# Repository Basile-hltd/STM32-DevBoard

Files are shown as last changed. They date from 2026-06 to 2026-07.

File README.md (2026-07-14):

# STM32 Dev Board

Carte de développement autour d'un microcontrôleur STM32, conçue pour l'acquisition de données environnementales, la communication industrielle et l'expansion vers breadboard ou systèmes embarqués tiers.

> **Contenu actuel du dépôt :**
>- projet KiCad (schématique + layout PCB).
>- Lib static HAL (propre à ce PCB).
>- Projects exemple (utilisant la lib)

---

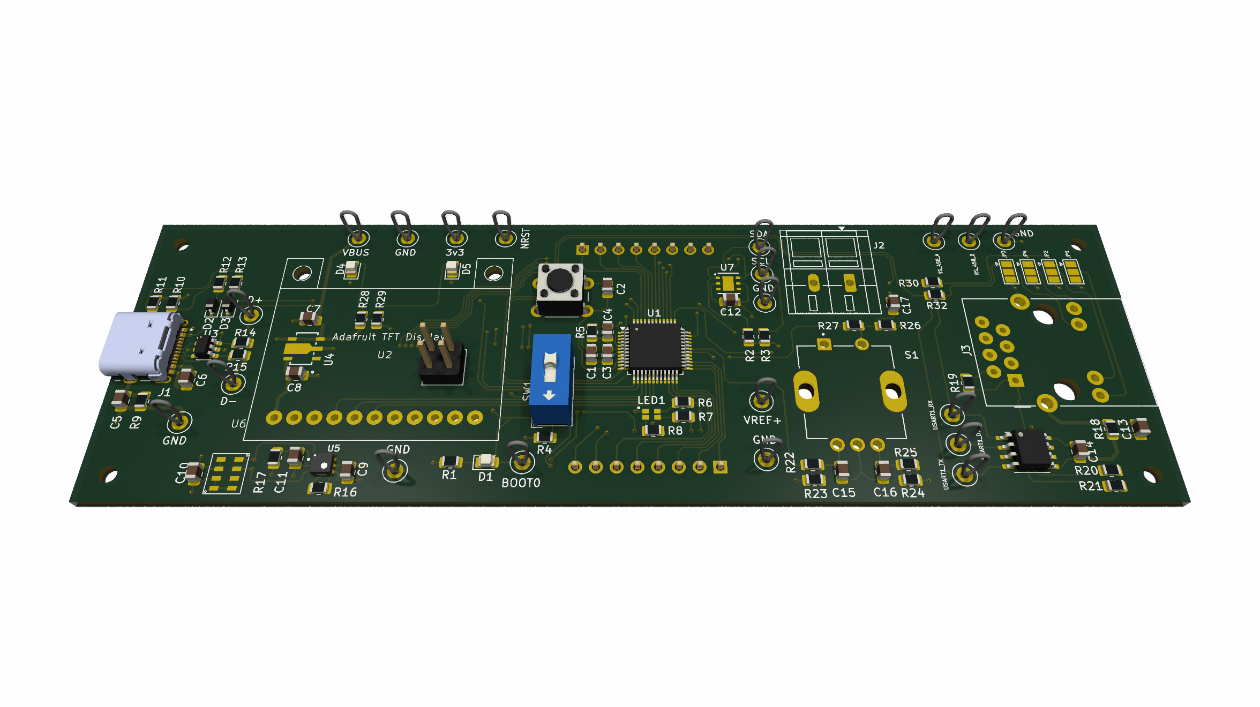
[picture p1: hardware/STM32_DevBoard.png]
Schéma bloc de la carte


## Fonctionnalités PCB

### I²C - Capteur
Quatre capteurs partagent le même bus I²C :
- Pression barométrique
- Qualité de l'air (COV / CO₂ équivalent)
- Température
- Humidité relative

### SPI - Affichage & stockage
- Écran (Color TFT 160x80)
- Carte microSD

### USB
Connecteur **USB-C** câblé directement au microcontrôleur (Full-Speed).

### RS-485
Port **RJ45** utilisé comme connecteur de terrain pour un bus **RS-485** :
- Piloté via **UART** du MCU
- **Pin de direction** (DE/RE) exposé pour la gestion half-duplex
- Alimentation **48 V** optionnelle injectée sur le bus RS-485 et sur le RJ45 via un connecteur **Wago** monté sur la carte (alimentation fantôme ou PoE industriel)

### Interface utilisateur
- **LED RGB**
- **Encodeur rotatif** avec bouton-poussoir

### Port B - Extension
Deux **pin headers 8 broches** (2 × 8 = 16 broches) exposant l'intégralité du **Port B** du STM32. Permet de connecter la carte à une breadboard, un shield ou tout autre sous-système externe sans soudure.

---

## Structure du dépôt

```
C:.
│   README.md
│   
├───documentation
│   │   .gitignore
│   │   *.pdf
│   │   
│   ├───datasheet
│   │       *.pdf
│   │       
│   └───script
│           Datasheet_Downloader.py
│           Digikey_Datasheet_List.csv
│           requirements.txt
│           
├───hardware
│   │   .gitignore
│   │   STM32_DevBoard.kicad_pcb
│   │   STM32_DevBoard.kicad_prl
│   │   STM32_DevBoard.kicad_pro
│   │   STM32_DevBoard.kicad_sch
│   │   STM32_DevBoard.pdf
│   │   STM32_DevBoard.png
│   │       
│   ├───3d_models
│   │       *.step
│   │       
│   ├───footprints
│   │       *.kicad_mod
│   │       
│   └───symbols
│           *.kicad_sym
│           
└───software
    │   .gitignore
    │   arm-none-eabi.cmake
    │   CMakeLists.txt
    │   stm32c0.ld
    │           
    ├───Blinky
    │   │   CMakeLists.txt
    │   │   
    │   └───src
    │           main.c
    │                       
    └───DevBoard_HAL
        │   CMakeLists.txt
        │   
        └───src
            │   init.c
            │   rgb_led.c
            │   startup.c
            │   
            └───headers
                    init.h
                    registers.h
                    rgb_led.h
                    STM32_DevBoard.h
                    
```

---

## Prérequis

- **KiCad 8.x** ou supérieur
- Bibliothèques KiCad standard 
- CMake
- arm-none-eabi
- dfu-util
- STM32Cube-Programmer
---

## Mise en route

### Compilation
crée un dossier build dans `software/`, initialiser cmake, puis compiler.

```
mkdir software/build
cd software/build
cmake -DCMAKE_TOOLCHAIN_FILE="../arm-none-eabi.cmake" ..
```
compiler avec :

```
cmake --build .
```

ou flasher avec

```
cmake --build . --target flash_{nom du dossier d'app}
cmake --build . --target flash_Blinky
```

Cela va buils le HAL ainsi que toutes la applications. Le premier build peut prendre plus de temps. Les binaire des applications se trouvent dans `software/bin/le_nom_de_lapp/`

---

## Futures Amleliorations

- Ajuster les dimension du PCB
- Réduire la taille du PCB
- Ajout de pin d'alimentation et de masse sur les pin du port B
- Diodes TVS et sécurité sur bus RS_485 (Alim et signaux)
- Implémenter protocole power delivery USB-C (48V sur usb-c et non wage par exemple ou que le STM32 puisse connaitre les capacité de l'alim)

---

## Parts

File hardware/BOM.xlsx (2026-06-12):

Reference | Qty | Value | In Degikey list
C1,C2,C3,C5,C6,C10,C12,C13,C14 | 9 | 100nF | Y
C4 | 1 | 4.7uF | Y
C7 | 1 | 10uF | Y
C8,C9,C11 | 3 | 1uF | Y
C15,C16,C17 | 3 | 10nF | Y
D1 | 1 | BOOT0_LED | Y
D2,D3 | 2 | CC
D4 | 1 | VBUS_LED
D5 | 1 | 3v3_LED
J1 | 1 | USB4105-GF-A
J2 | 1 | Screw_Terminal_01x02
J3 | 1 | RJ45_LED_Shielded
J5 | 1 | Port_B_1
J6 | 1 | Port_B_2
LED1 | 1 | IN-S66TBTRGB
R1 | 1 | 150
R2,R3 | 2 | 3k3
R4,R22,R23,R24,R25,R26,R27 | 7 | 10k
R5,R16 | 2 | 0
R6,R28 | 2 | 560
R7,R8 | 2 | 360
R9,R18 | 2 | 1M
R10,R11 | 2 | 5k1
R12,R13 | 2 | 100
R14,R15 | 2 | 22
R17 | 1 | 4.7
R19 | 1 | 120
R20,R21 | 2 | 1k
R29 | 1 | 220
S1 | 1 | PEC12R-4217F-S0012
SW1 | 1 | SW_SPST
SW2 | 1 | SW_MEC_5G
TP1,TP7,TP8,TP13,TP14,TP18 | 6 | GND
TP2 | 1 | SDA
TP3 | 1 | SCL
TP4 | 1 | BOOT0
TP5 | 1 | VREF+
TP6 | 1 | NRST
TP9 | 1 | D+
TP10 | 1 | D-
TP11 | 1 | VBUS
TP12 | 1 | 3v3
TP15 | 1 | USART1_DE
TP16 | 1 | USART1_RX
TP17 | 1 | USART1_TX
TP19 | 1 | RS_458_B
TP20 | 1 | RS_458_A
U1 | 1 | STM32C071CBTx
U2 | 1 | DISPLAY TFT
U3 | 1 | USBLC6-2SC6
U4 | 1 | AP2112R5-3.3TRG1
U5 | 1 | SGP40-D-R4
U6 | 1 | MS5607-02BA
U7 | 1 | HDC1080
U8 | 1 | TP8485E-SR

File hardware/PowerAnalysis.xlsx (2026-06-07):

 |  |  |  |  |  |  |  | VBUS
3.3 | V |  |  |  |  | mA | mW | 5 | V |  |  |  |  | mA | mW
 |  | Name | Current[mA] | Power [mW] | Total | 140.553 | 463.8249 |  |  | Name | Current[mA] | Power [mW] | Total | 160.613 | 803.065
 |  | I2C | 2 | 6.6 |  |  |  |  |  | Led RGB | 15 | 75
 |  | STM32 | 100 | 330 |  |  |  |  |  | Led Alim | 5 | 25
 |  | BOOT0 | 0.33 | 1.089 |  |  |  |  |  | AP211 | 140.613 | 703.065
 |  | Screen | 25 | 82.5
 |  | Alim LED | 5 | 16.5
 |  | SGP40 | 3 | 9.9
 |  | HDC1080 | 0.22 | 0.726
 |  | MS5607 | 0.013 | 0.0429
 |  | TP8485 | 1 | 3.3
 |  | LED RJ45 | 3 | 9.9
 |  | Encodeur | 0.99 | 3.267

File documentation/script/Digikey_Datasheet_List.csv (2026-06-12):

Index | Référence fabricant | Nom du fabricant | Description | Fiche technique | Notes sur le produit
1 | CL21B104KBCNNNC | Samsung Electro-Mechanics | CAP CER 0.1UF 50V X7R 0805 | https://mm.digikey.com/Volume0/opasdata/d220001/medias/docus/609/CL21B104KBCNNN_Spec.pdf
2 | CL21A475KPFNNNE | Samsung Electro-Mechanics | CAP CER 4.7UF 10V X5R 0805 | https://weblib.samsungsem.com/mlcc/mlcc-ec-data-sheet.do?partNumber=CL05Y105KP6VPN
3 | CL21A106KPFNNNG | Samsung Electro-Mechanics | CAP CER 10UF 10V X5R 0805 | https://mm.digikey.com/Volume0/opasdata/d220001/medias/docus/658/CL21A106KPFNNNG.pdf
4 | CL21B105KAFNNNE | Samsung Electro-Mechanics | CAP CER 1UF 25V X7R 0805 | https://mm.digikey.com/Volume0/opasdata/d220001/medias/docus/1105/CL21B105KAFNNNE_Spec.pdf
5 | CL21B103KBANNNC | Samsung Electro-Mechanics | CAP CER 10000PF 50V X7R 0805 | https://www.samsungsem.com/kr/support/product-search/mlcc/CL21B103KBANNNC.jsp
6 | LTST-C170KRKT | Lite-On Inc. | LED RED CLEAR SMD | https://optoelectronics.liteon.com/upload/download/DS-22-99-0150/LTST-C170KRKT.pdf
7 | SDB13HS-AQ | Diotec Semiconductor | DIODE SCHOTTKY 30V 1A SOD323F | https://diotec.com/request/datasheet/sdb13hs.pdf
8 | LTST-C170KGKT | Lite-On Inc. | LED GREEN CLEAR SMD | https://optoelectronics.liteon.com/upload/download/DS22-2000-073/LTST-C170KGKT.pdf
9 | USB4105-GF-A | GCT | CONN RCP USB2.0 TYP C 16P SMD RA | https://gct.co/files/specs/usb4105-spec.pdf
10 | 236-102 | WAGO Corporation | PCB TERMINAL BLOCK; 2.5 MM; PIN | https://wago.priintcloud.com/datasheets/236-102/en/
11 | MTJ-88TX1-FSD-LG | Adam Tech | RJ45 MODULAR JACK, SHIELDED, DIP | https://app.adam-tech.com/products/download/data_sheet/203933/mtj-88tx1-fsd-lg-data-sheet.pdf
12 | 61300811121 | Würth Elektronik | CONN HEADER VERT 8POS 2.54MM | https://www.we-online.com/components/products/datasheet/61300811121.pdf
13 | IN-S66TBTRGB | Inolux | LED RGB CLEAR 0606 SMD | http://www.inolux-corp.com/datasheet/SMDLED/RGB%20Top%20View/IN-S66TBTRGB_V1.0.pdf
14 | RC0805FR-07150RL | YAGEO | RES 150 OHM 1% 1/8W 0805 | https://yageogroup.com/content/datasheet/asset/file/PYU-RC_GROUP_51_ROHS_L
15 | ERA-6AEB332V | Panasonic Industry | RES SMD 3.3K OHM 0.1% 1/8W 0805 | https://industrial.panasonic.com/cdbs/www-data/pdf/RDM0000/AOA0000C307.pdf
16 | RC0805FR-0710KL | YAGEO | RES 10K OHM 1% 1/8W 0805 | https://yageogroup.com/content/datasheet/asset/file/PYU-RC_GROUP_51_ROHS_L
17 | RMCF0805ZT0R00 | Stackpole Electronics Inc | RES 0 OHM JUMPER 1/8W 0805 | https://www.seielect.com/catalog/SEI-RMCF_RMCP.pdf
18 | ERJ-6GEYJ561V | Panasonic Industry | RES SMD 560 OHM 5% 1/8W 0805 | https://industrial.panasonic.com/cdbs/www-data/pdf/RDA0000/AOA0000C301.pdf
19 | RC0805JR-07360RL | YAGEO | RES 360 OHM 5% 1/8W 0805 | https://yageogroup.com/content/datasheet/asset/file/PYU-RC_GROUP_51_ROHS_L
20 | RG2012P-105-B-T5 | Susumu | RES SMD 1M OHM 0.1% 1/8W 0805 | https://www.susumu.co.jp/dl/?filename=n_catalog_partition01_en.pdf&type=application/pdf
21 | RC0805JR-075K1L | YAGEO | RES 5.1K OHM 5% 1/8W 0805 | https://yageogroup.com/content/datasheet/asset/file/PYU-RC_GROUP_51_ROHS_L
22 | RC0805FR-07100RL | YAGEO | RES 100 OHM 1% 1/8W 0805 | https://yageogroup.com/content/datasheet/asset/file/PYU-RC_GROUP_51_ROHS_L
23 | RC0805FR-0722RL | YAGEO | RES 22 OHM 1% 1/8W 0805 | https://yageogroup.com/content/datasheet/asset/file/PYU-RC_GROUP_51_ROHS_L
24 | RC0805JR-074R7L | YAGEO | RES 4.7 OHM 5% 1/8W 0805 | https://yageogroup.com/content/datasheet/asset/file/PYU-RC_GROUP_51_ROHS_L
25 | CRCW0805120RJNEA | Vishay Dale | RES SMD 120 OHM 5% 1/4W 0805 | https://www.vishay.com/docs/20035/dcrcwe3.pdf
26 | CRGCQ0805F220R | TE Connectivity Passive Product | RES 220 OHM 1% 1/8W 0805 | https://www.te.com/commerce/DocumentDelivery/DDEController?Action=srchrtrv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
27 | RR1220P-102-D | Susumu | RES SMD 1K OHM 0.5% 1/10W 0805 | https://www.susumu.co.jp/common/pdf/n_catalog_partition05_en.pdf
28 | PEC12R-4217F-S0012 | Bourns Inc. | ENCODER INCRE QUAD HORIZN PC PIN | https://www.bourns.com/docs/Product-Datasheets/PEC12R.pdf
29 | DS04-254-1L-01BK | Same Sky (Formerly CUI Devices) | SWITCH SLIDE DIP SPST 0.025A 24V | https://www.sameskydevices.com/product/resource/ds04-254.pdf
30 | TS02-66-50-BK-160-SCR-D | Same Sky (Formerly CUI Devices) | SWITCH TACTILE SPST-NO 0.05A 12V | https://www.sameskydevices.com/product/resource/ts02.pdf
31 | 4952 | Keystone Electronics | PC TEST POINT LOOP | https://www.keyelco.com/userAssets/file/K75p63.pdf
32 | STM32C071CBT7 | STMicroelectronics | STM32C | https://www.st.com/resource/en/datasheet/stm32c071r8.pdf
33 | 3533 | Adafruit Industries LLC | GRAPHIC DISPLAY TFT RGB 0.96" | https://cdn-learn.adafruit.com/downloads/pdf/adafruit-mini-tft-0-dot-96-inch-180x60-breakout.pdf
34 | USBLC6-2SC6 | Shenzhen Slkormicro Semicon Co., Ltd. | 6A@8/20US 13V 78W@8/20US 9V 5V S | https://mm.digikey.com/Volume0/opasdata/d220001/medias/docus/7833/USBLC6-2SC6%20SOT-23-6L.PDF
35 | AP2112R5-3.3TRG1 | Diodes Incorporated | IC REG LINEAR 3.3V 600MA SOT89-5 | https://www.diodes.com/assets/Datasheets/AP2112.pdf
36 | SGP40-D-R4 | Sensirion AG | SENSOR AIR QUALITY I2C OUTPUT | https://sensirion.com/media/documents/296373BB/6203C5DF/Sensirion_Gas_Sensors_Datasheet_SGP40.pdf
37 | MS560702BA03-50 | TE Connectivity Measurement Specialties | SENSOR 17.4PSIA 24BIT 8SMD | https://www.te.com/commerce/DocumentDelivery/DDEController?Action=srchrtrv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
38 | HDC1080DMBR | Texas Instruments | SENSOR HUMI/TEMP 3.3V I2C 2% SMD | https://www.ti.com/general/docs/suppproductinfo.tsp?distId=10
39 | TP8485E-SR | 3PEAK | IC TRANSCEIVER HALF 1/1 8SOIC | https://static.3peak.com/res/doc/ds/Datasheet_TP8485E.pdf

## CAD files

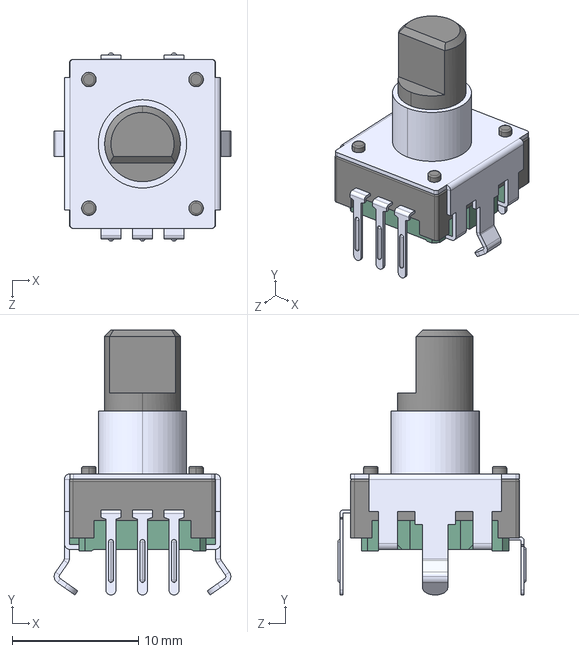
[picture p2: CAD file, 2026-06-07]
hardware/3d_models/PEC12R-4217F-S0012.step
14.0 x 21.0 x 14.9 mm

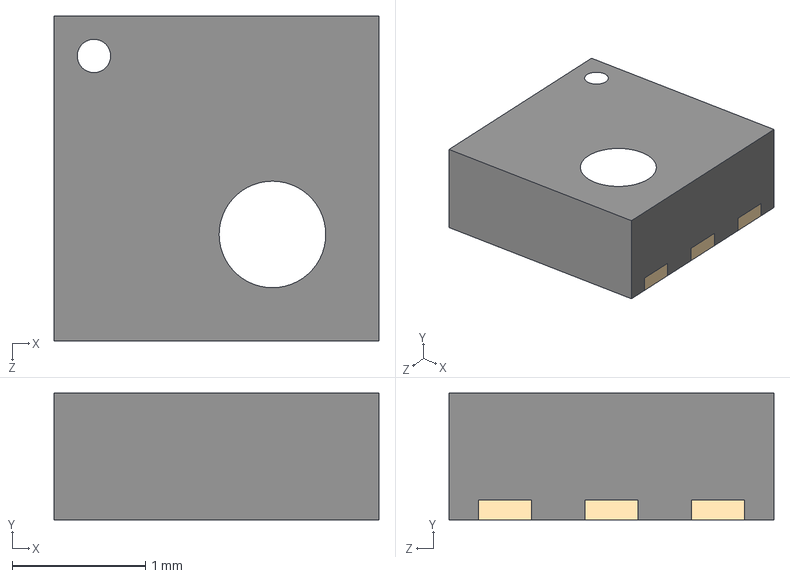
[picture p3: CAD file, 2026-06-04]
hardware/3d_models/SGP40-D-R4.step
2.44 x 0.95 x 2.44 mm

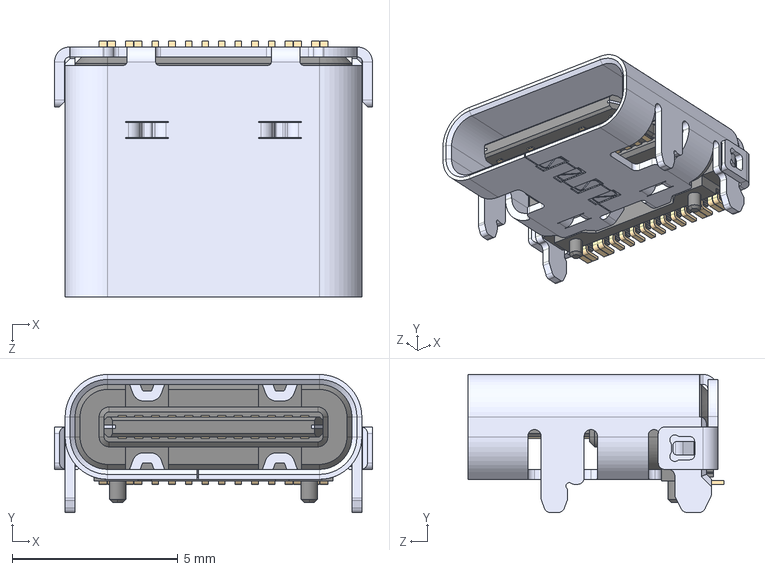
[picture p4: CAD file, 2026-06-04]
hardware/3d_models/USB4105-GF-A.step
9.58 x 4.16 x 7.71 mm

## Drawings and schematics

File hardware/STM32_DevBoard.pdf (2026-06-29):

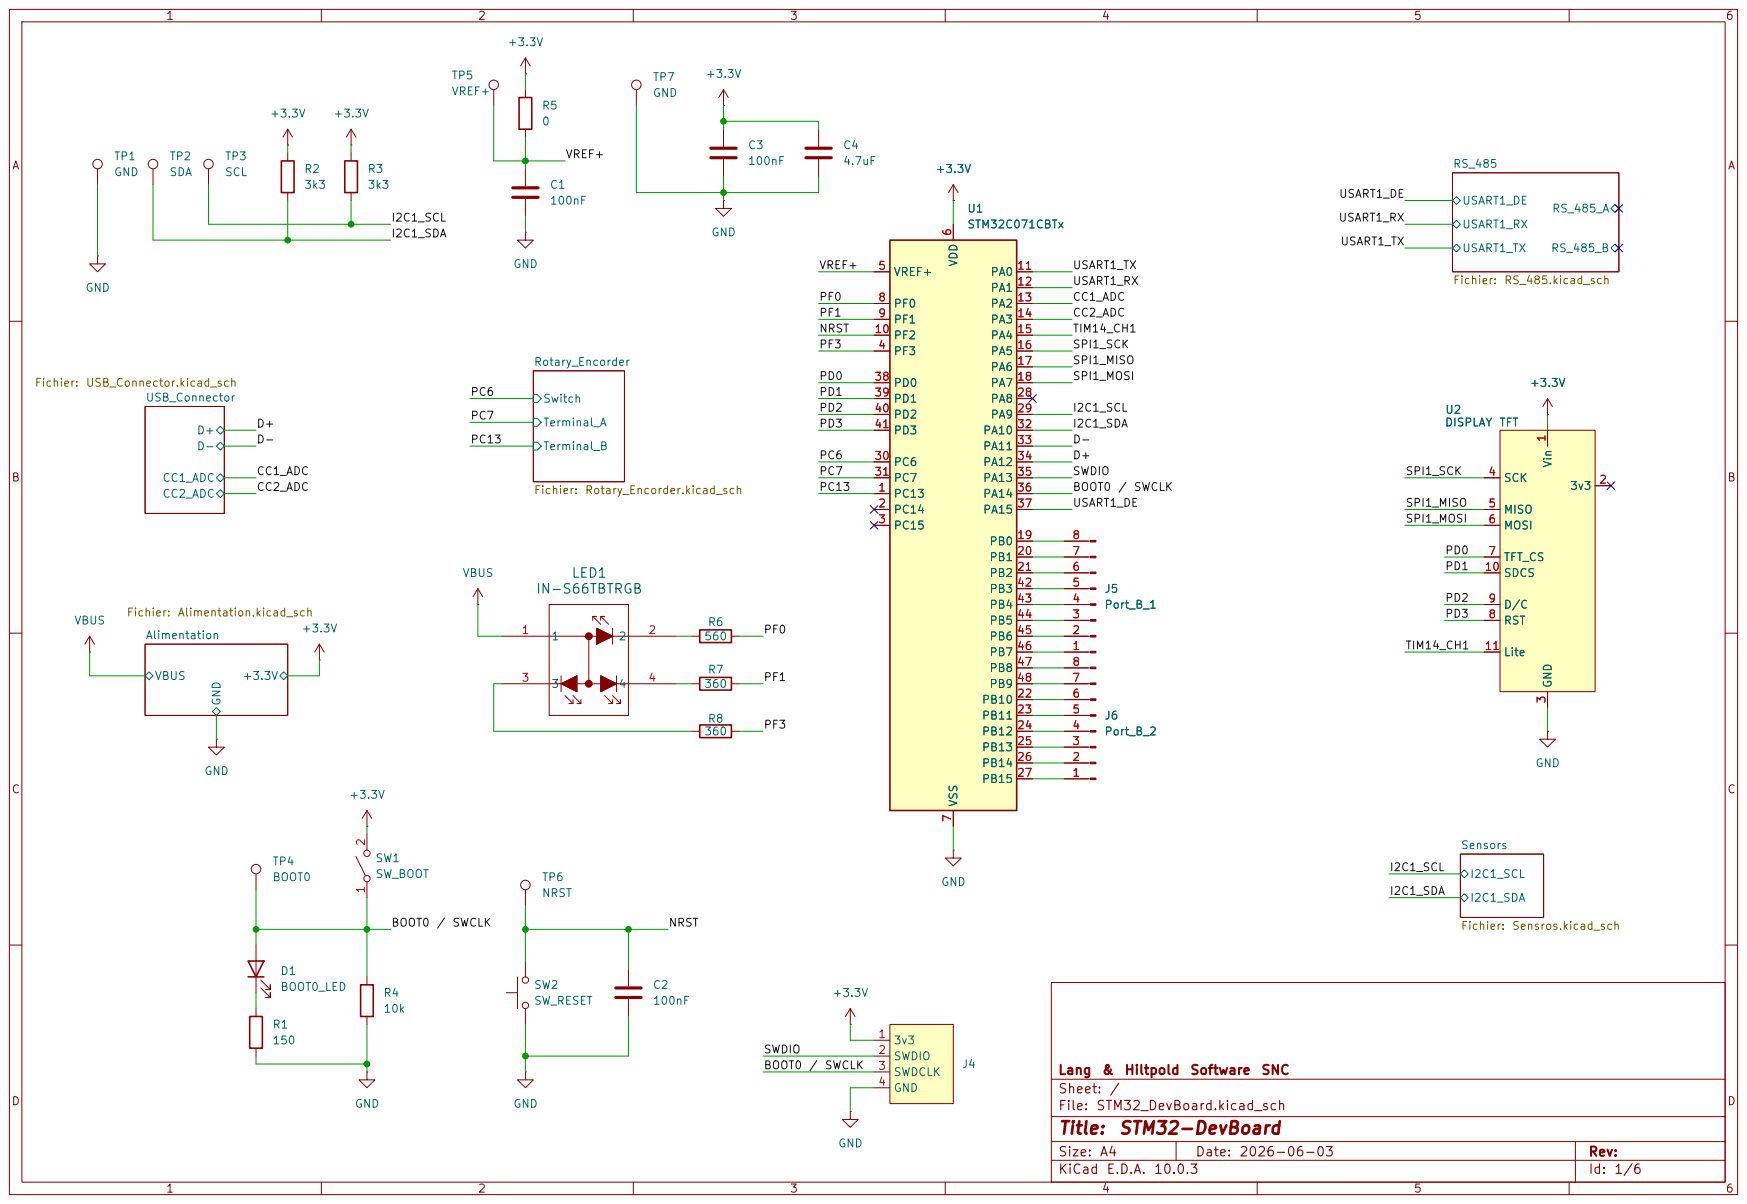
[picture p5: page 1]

Lang & Hiltpold Software SNC
Sheet: /
File: STM32_DevBoard.kicad_sch
Title: STM32-DevBoard

Size: A4 | Rev:
KiCad E.D.A. 10.0.3 | Id: 1/6

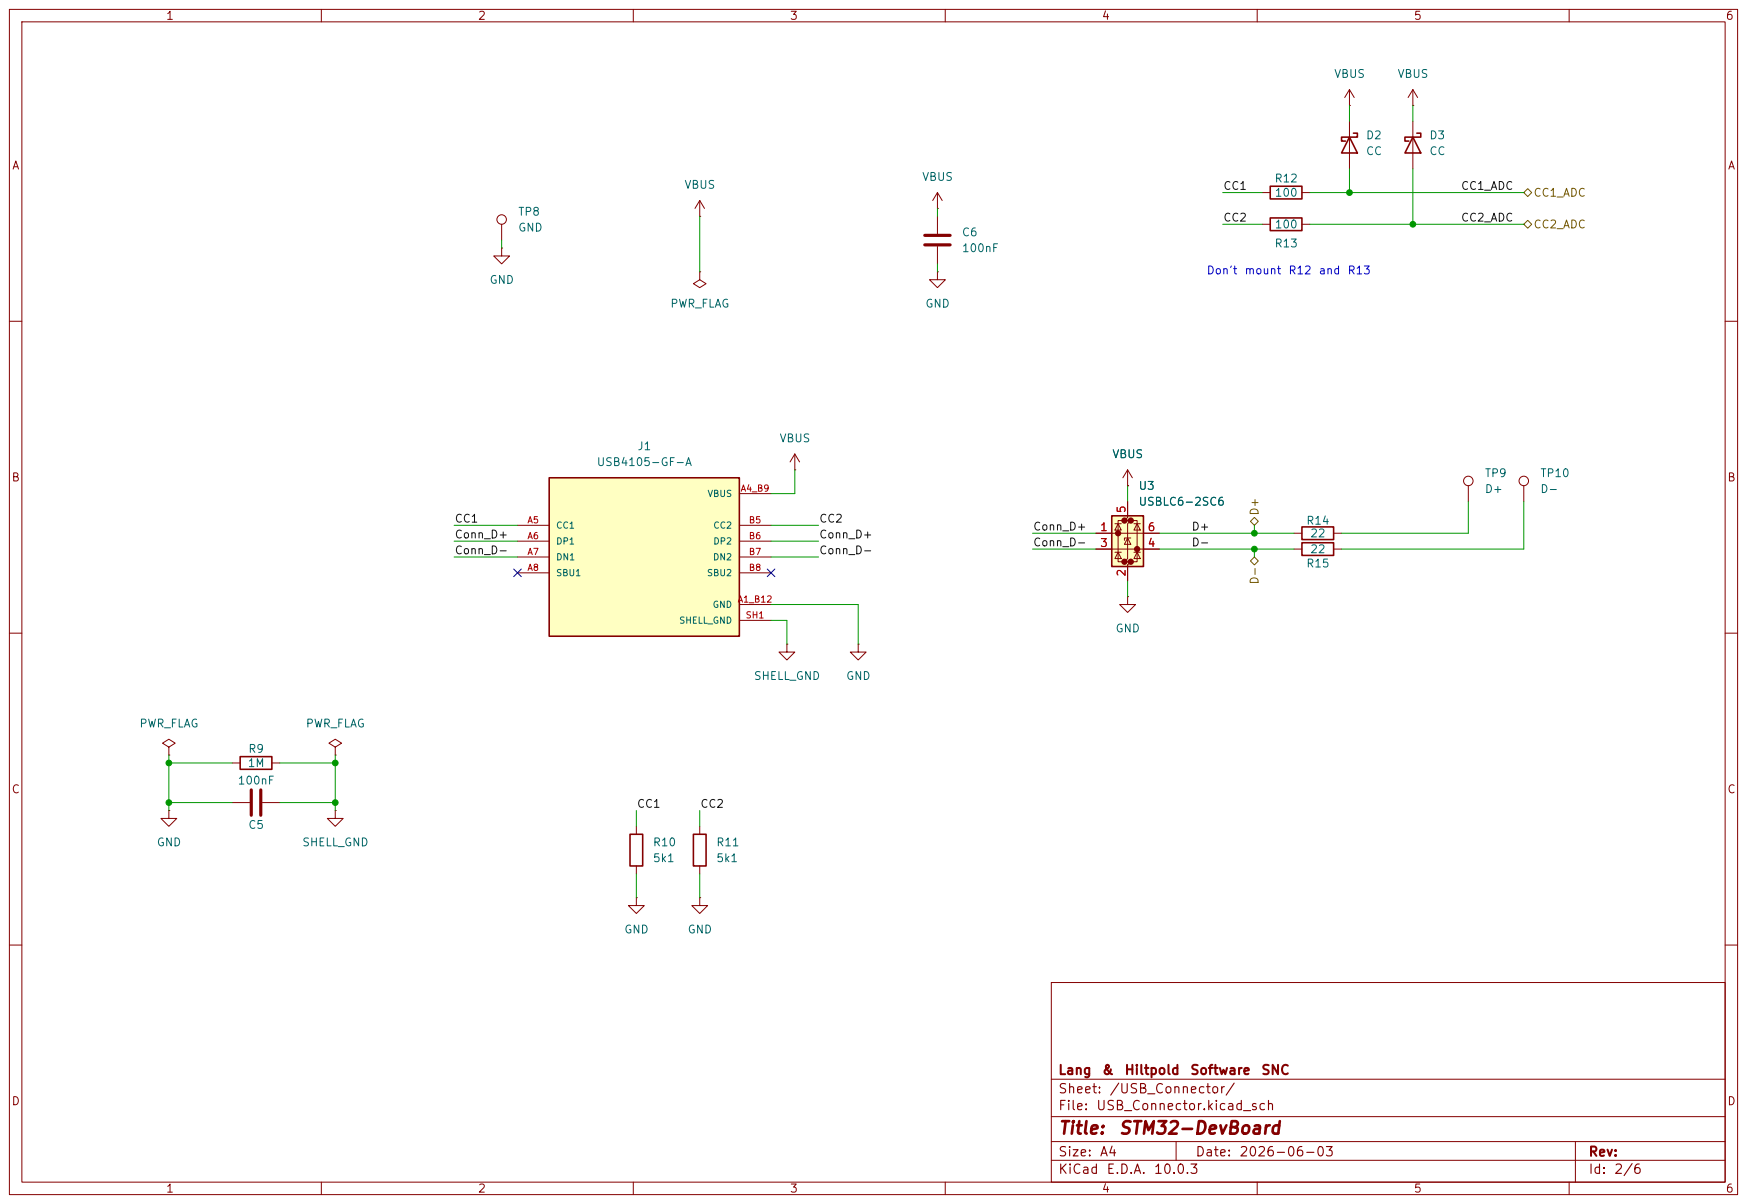
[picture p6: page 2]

Lang & Hiltpold Software SNC
Sheet: /USB_Connector/
File: USB_Connector.kicad_sch
Title: STM32-DevBoard

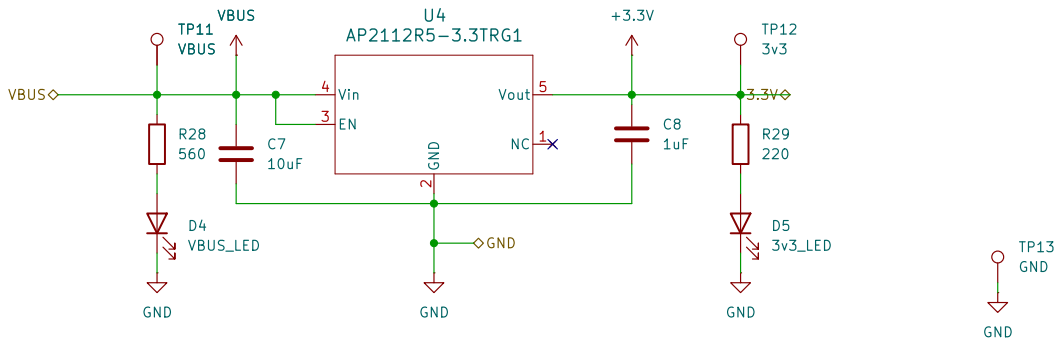
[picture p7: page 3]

Lang & Hiltpold Software SNC
Sheet: /Alimentation/
File: Alimentation.kicad_sch
Title: STM32-DevBoard

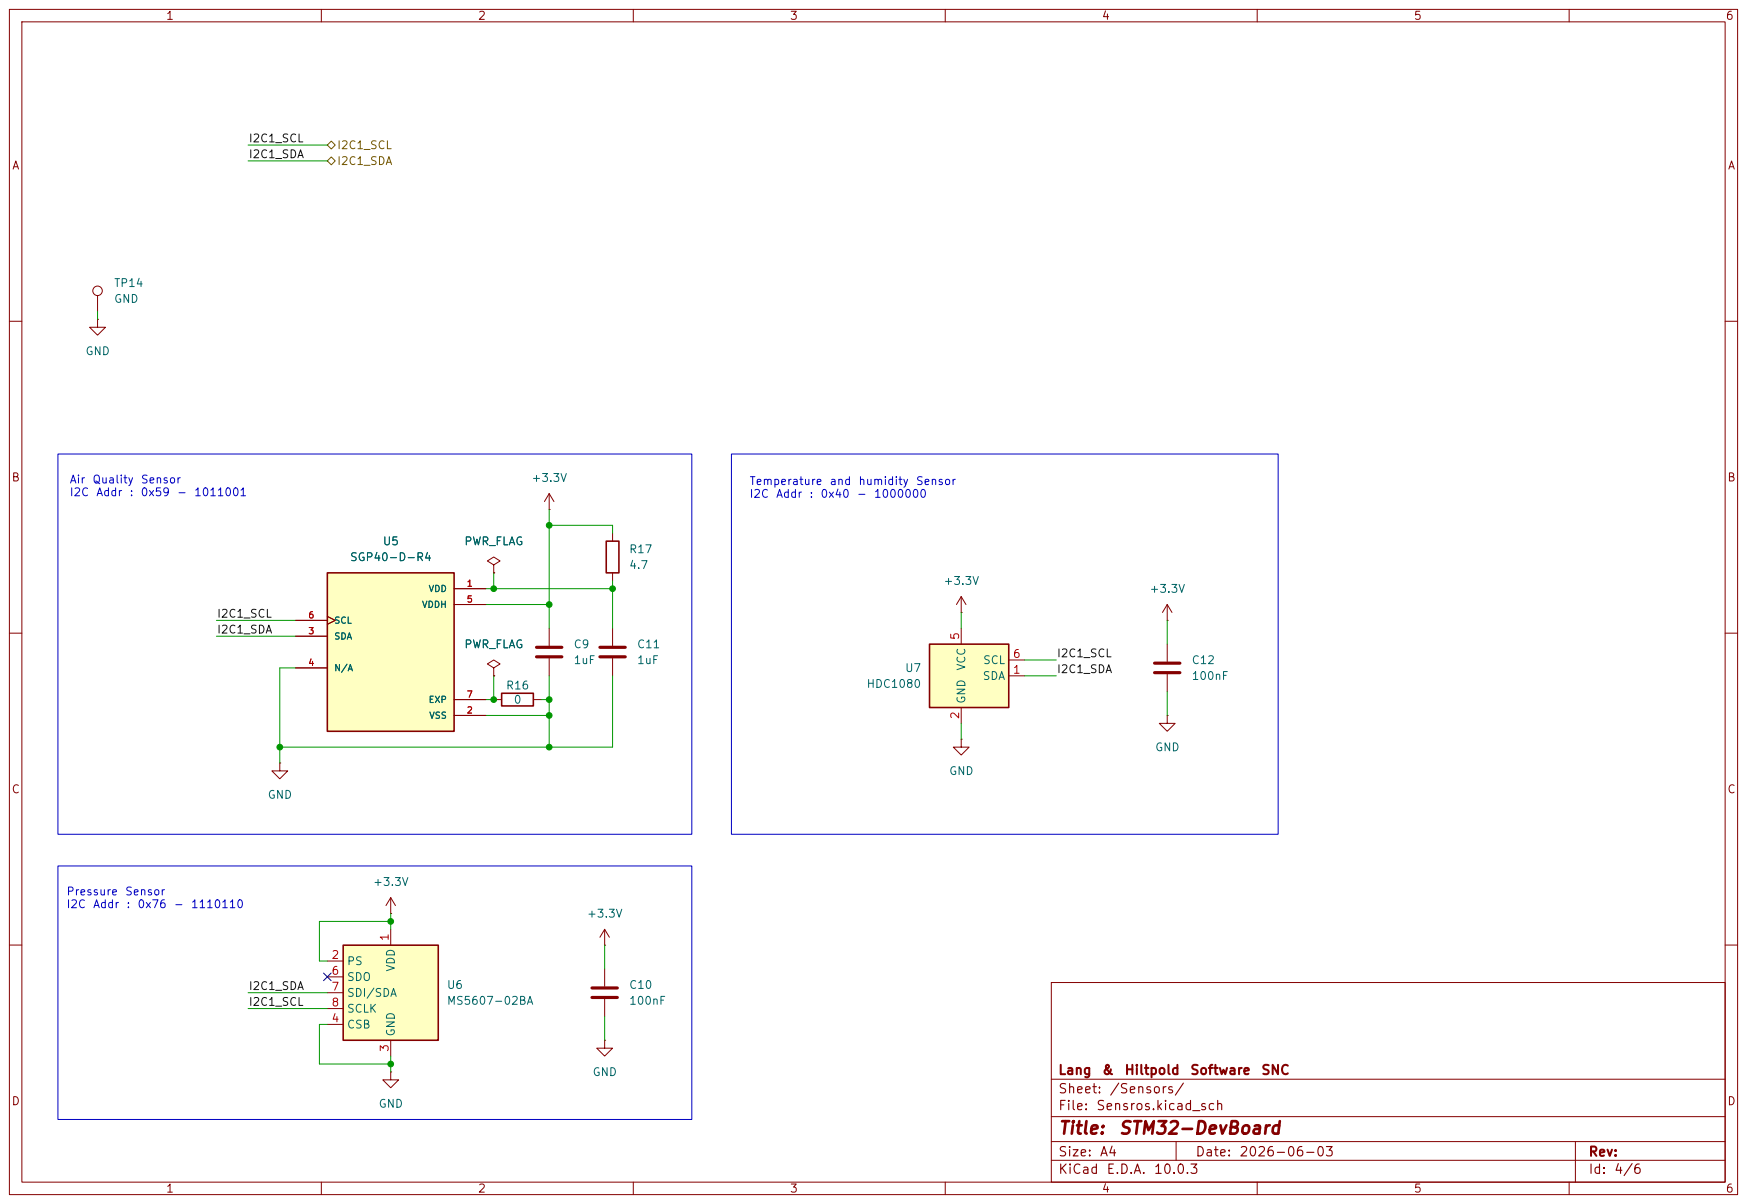
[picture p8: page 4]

Temperature and humidity Sensor

Lang & Hiltpold Software SNC
Sheet: /Sensors/
File: Sensros.kicad_sch
Title: STM32-DevBoard

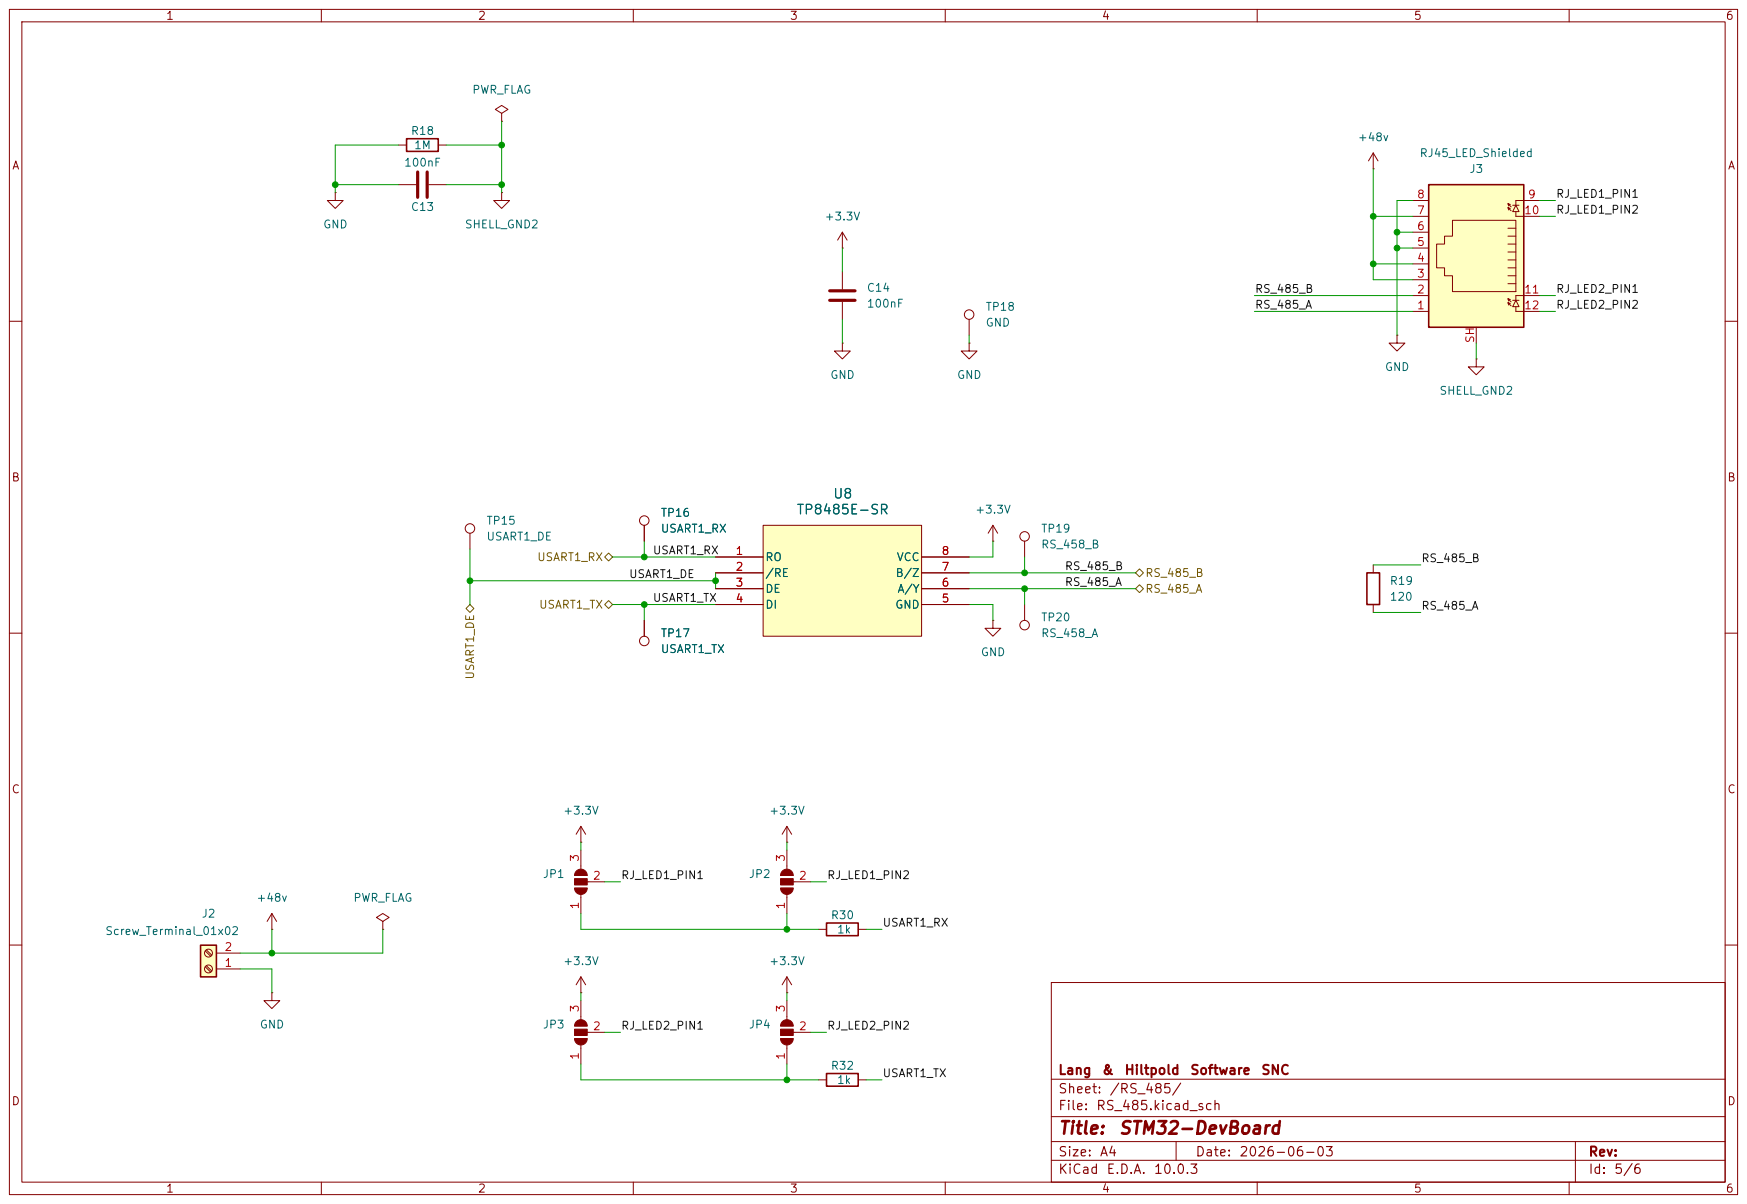
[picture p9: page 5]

Lang & Hiltpold Software SNC
Sheet: /RS_485/
File: RS_485.kicad_sch
Title: STM32-DevBoard

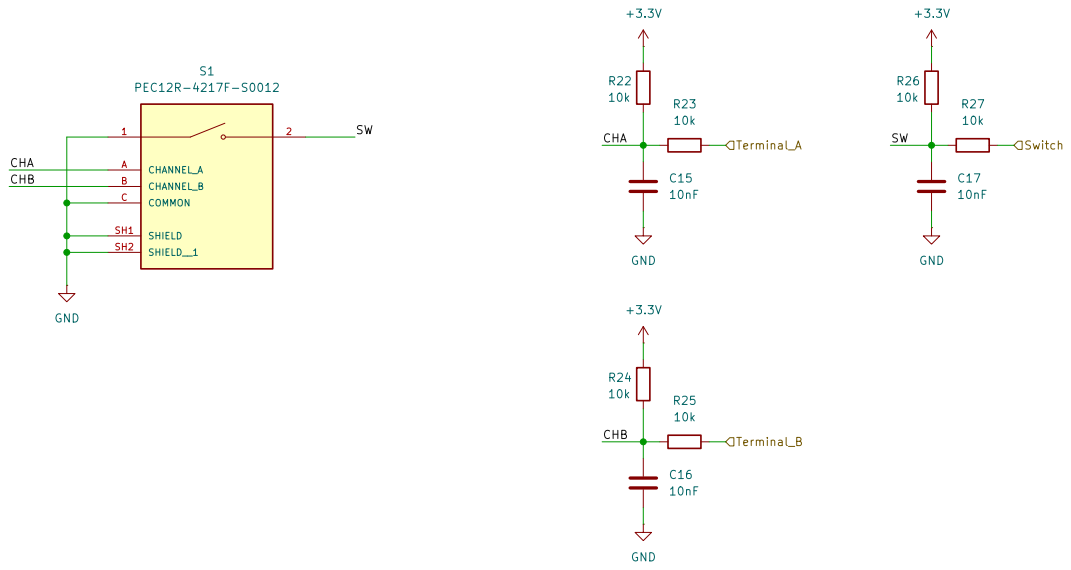
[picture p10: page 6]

Lang & Hiltpold Software SNC
Sheet: /Rotary_Encorder/
File: Rotary_Encorder.kicad_sch
Title: STM32-DevBoard

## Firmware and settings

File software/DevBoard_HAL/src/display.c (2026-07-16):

#include "STM32_DevBoard.h"

void set_x_bounding(uint16_t start, uint16_t end){
    st7735_spi_write_cmd(0x2A);

    st7735_spi_write_data(start >> 8);
    st7735_spi_write_data(start);
    st7735_spi_write_data(end >> 8);
    st7735_spi_write_data(end);
}

void set_y_bounding(uint16_t start, uint16_t end){
    st7735_spi_write_cmd(0x2B);

    st7735_spi_write_data(start >> 8);
    st7735_spi_write_data(start);
    st7735_spi_write_data(end >> 8);
    st7735_spi_write_data(end);
}

void fill_screen_rgb565(uint8_t red, uint8_t green, uint8_t blue){

    set_x_bounding(1, 1+ST7735_WIDTH-1);
    set_y_bounding(26, 26+ST7735_HEIGHT-1);

    st7735_spi_write_cmd(0x2C);
    st7735_dc_data();
    st7735_cs_low();
    for (unsigned char y = 0; y < ST7735_HEIGHT; y++){
        for (unsigned char x = 0; x < ST7735_WIDTH; x++){
            spi1_transfer(red << 3 | (green>>3)); 
            spi1_transfer(red << 5 | blue); 
        }
    }
    st7735_cs_high();

}

void draw_char(unsigned char x, unsigned char y, char c){
    
    const uint16_t* bitmap = NULL;

    if (c >= '0' && c <= '9'){
        bitmap = num_font[c-0x30]; 
    }
    else{
        return;
    }

    set_x_bounding(1+x*10, 1+x*10 + 9);
    set_y_bounding(26+y*10, 26+y*10 + 9);    

    st7735_spi_write_cmd(0x2C);
    st7735_dc_data();
    st7735_cs_low();
    for (unsigned char y = 0; y < 10; y++){
        for (unsigned char x = 0; x < 10; x++){
            if (bitmap[y] & (1 << (9 - x))){
                spi1_transfer(0xff);  
                spi1_transfer(0xff);
            }
            else{
                spi1_transfer(0x00);  
                spi1_transfer(0x00); 
            }
        }
    }
    st7735_cs_high();
}

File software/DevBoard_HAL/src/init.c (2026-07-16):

#include "STM32_DevBoard.h"

void STM32_DevBoard_HAL_Init(void){

    //========== Flash init ==========

    FLASH_ACR |= 0x00000001;        // xxxxxxxx xxxxxxxx xxxxxxxx xxxxxxx1
    while ((FLASH_ACR & 0x00000001) == 0);

    //========== END Flash init ==========

    //========== Clock init ==========

    RCC_CR &= ~0x00003800;             // xxxxxxxx xxxxxxxx xx000xxx xxxxxxxx
    while ((RCC_CR & 0x00003800) >= 1);

    RCC_APBENR1 |= 0x00000001;      // xxxxxxxx xxxxxxxx xxxxxxxx xxxxxxx1
    while ((RCC_APBENR1 & 0x00000001) == 0);

    RCC_APBENR2 |= 0x00001000;      // xxxxxxxx xxxxxxxx xxx1xxxx xxxxxxxx
    while ((RCC_APBENR2 & 0x00001000) == 0);

    //========== END Clock init ==========

    //========== RGB_Led init ==========

    RCC_IOPENR |=  0x0000002F;      // xxxxxxxx xxxxxxxx xxxxxxxx xx1x1111 

    GPIOF_MODER &=  ~0x000000CF;    // xxxxxxxx xxxxxxxx xxxxxxxx 00xx0000 
    GPIOF_MODER |=  0x00000045;     // xxxxxxxx xxxxxxxx xxxxxxxx 01xx0101
    
    GPIOF_OTYPER |= 0x0000000B;     // xxxxxxxx xxxxxxxx xxxxxxxx xxxx1011

    //========== END RGB_Led init ==========
    
    //========== Delay init ==========

    TIM2_PSC = 48000 - 1;           // (PSC+1) = 48 → 48MHz/48000 = 1kHz → tick = 1ms
    TIM2_ARR = 0xFFFFFFFF;
    TIM2_CR1 |= 0x0084;             // xxxx0x00 10000100 

    TIM2_EGR |= 0x0001;
    TIM2_SR &= ~0x0001;

    TIM2_CR1 |= 0x0001;             // xxxxxxxx xxxxxxx1 

    TIM2_CNT = 0;

    //========== END Delay init ========== 

    //========== SPI1 init ==========

    GPIOA_MODER &= ~0x0000FC00;     //xxxxxxxx xxxxxxxx 101010xx xxxxxxxx
    GPIOA_MODER |= 0x0000A800;      //xxxxxxxx xxxxxxxx 101010xx xxxxxxxx

    GPIOA_OSPEEDR |= 0x0000FC00;    //xxxxxxxx xxxxxxxx 111111xx xxxxxxxx

    GPIOA_AFRL &= ~0xFFF00000;      //00000000 0000xxxx xxxxxxxx xxxxxxxx

    GPIOD_MODER &= ~0x000000F3;     //xxxxxxxx xxxxxxxx xxxxxxxx 1111xx01
    GPIOD_MODER |= 0x00000051;      //xxxxxxxx xxxxxxxx xxxxxxxx 0101xx01

    GPIOD_OSPEEDR |= 0x000000F3;    //xxxxxxxx xxxxxxxx xxxxxxxx 1111xx11

    GPIOD_ODR |= 0x0000000D;        //xxxxxxxx xxxxxxxx xxxxxxxx xxxx11X1

    SPI1_CR1 = 0x034C;              //00000011 0100 1100
    SPI1_CR2 &= ~0x7FFF;            //x0010111 00000000
    SPI1_CR2 |= 0x1700;             //x0010111 00000000 

    //========== END SPI1 init ========== 

    RGB_Off();
    st7735_init();
}

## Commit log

2026-06-04 plein de truc chouette
    [SGP40-D-R4.step, STM32_DevBoard.kicad_pcb, STM32_DevBoard.kicad_sch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]
2026-06-06 encore plein de truc chouette
    [Alimentation.kicad_sch, RS_485.kicad_sch, STM32_DevBoard.kicad_sch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]
2026-06-07 Schema termine ?
    [PEC12R-4217F-S0012.step, PowerAnalysis.xlsx, RS_485.kicad_sch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]
2026-06-07 Assignation terminee
    [Alimentation.kicad_sch, BOM.xlsx, RS_485.kicad_sch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]
2026-06-07 Start routing pcb
    [RS_485.kicad_sch, STM32_DevBoard.kicad_pcb, STM32_DevBoard.kicad_sch]
2026-06-07 PCB routing....
    [STM32_DevBoard.kicad_pcb]
2026-06-08 PCB V1 Terminee
    [RS_485.kicad_sch, STM32_DevBoard.kicad_pcb]
2026-06-12 update BOM
    [BOM.xlsx, STM32_DevBoard.kicad_pcb, STM32_DevBoard_BOM.csv]
2026-06-12 Add datasheets
    [Digikey_Datasheet_List.csv]
2026-06-24 USB connector CC Resistor not mount text added
    [Alimentation.kicad_sch, USB_Connector.kicad_sch]
2026-06-29 Add schematic pdf
2026-06-30 C bare metal led blink
2026-07-16 Print program size
